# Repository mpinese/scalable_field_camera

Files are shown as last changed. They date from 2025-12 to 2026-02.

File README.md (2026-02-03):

# An Opinionated Remix of Edgar Kech's _Scalable large format field camera_

Edgar Kech has gifted the community an outstanding design in his [Scalable Field Camera](https://github.com/edgarkech/scalable_field_camera).

This is my personal remix of Edgar's work, with quality-of-life tweaks, more robust mechanical fixtures, and bugfixes. If printed in the recommended filament this camera is exceptionally lightweight, being 965 g (2.1 lb) including bellows and ground glass. I've used it in multiple photo trips now with no issues.

My remix is focused on 4&times;5 cameras only and will need tweaking for larger formats. If you're looking to print a larger camera, consider Edgar's original design.

## Changes from the original design:
- Exceptionally lightweight: 965g with bellows and ground glass.
- Threaded heat-set inserts used throughout; no more screwing into plastic.
- 3D printed knobs and lensboard, to remove reliance on hard-to-source parts.
- A more streamlined hinge.
- (Work in progress!) Harmonising the fasteners used, in an attempt to simplify the Bill of Materials.
- Many minor bugfixes
- Reorganised the source to better report the components used.
- A handle!

## Bill of Materials:
- 3D printer filament, see below for notes on filament choice. < 1 kg of filament will be needed in all cases. A small amount of TPU will be needed for the handle.
- Bellows. I followed the [Standard Camera bellows guide](https://standardcameras.com/pages/how-to-make-a-bellows) and it worked well. Note however that it's critical that the bellows material be as thin as possible; if it's too thick, the camera will not be able to close. I had success with ripstop nylon for the outer, and a very thin synthetic material used to blackout windows (black on one side, silver on the other) -- together these two were only 0.14 mm thick.
- Ground glass, 127 x 101 mm
- 600mm of 1.25mm spring steel wire
- 100mm of 0.75mm spring steel wire
- 1x brass T6 leadscrew nut (as are common on 3D printers). Ideally a double-trimmed flange type or else you will need to cut off two sides of the circular flange in order for it to fit.
- 1x T6 leadscrew, length 150 mm. Ensure that the leadscrew and nut are compatible (ie same lead and pitch).
- 3x plain washer, 6 mm, 0.8 mm thick
- 1x spring washer, 6 mm
- 1x carbon fibre rod, solid, 4 mm OD, >= 160 mm long
- 2x grub screw, M5 x 5 mm
- 4x button head machine screw, M3 x 8 mm
- 12x button head machine screw, M2 x 8 mm
- 4x countersunk machine screw, M3 x 6 mm
- 4x countersunk machine screw, M3 x 8 mm
- 23x countersunk machine screw, M3 x 10 mm
- 2x countersunk machine screw, M5 x 16 mm
- 4x countersunk machine screw, M5 x 20 mm
- 8x grub screw, M3 x 5 mm
- 10x grub screw, M3 x 8 mm
- 1x hex nut, M5
- 12x heat set insert, M2 x 3.5 x 3 (3.5 mm OD, 3 mm depth)
- 56x heat set insert, M3 x 5 x 4 (5 mm OD, 4 mm depth) -- sometimes called the "Voron" size
- 8x heat set insert, M5 x 7 x 5 (7 mm OD, 5 mm depth)

All parts are easily sourced from AliExpress.

## Filament
I used and recommend Siraya Tech's PPA-CF for this build: it is lightweight, strong, and stiff. However, it is also expensive and requires a printer with a heated chamber.

ABS is a cheaper option than PPA-CF, though it also requires a heated chamber printer, and it will likely require thicker walls than PPA-CF, thus increasing weight.

If you do not have access to a heated chamber printer then the next best option would be PLA, ideally filled (eg PLA-CF) for best printability. However, bear in mind that a PLA body will be both heavier, and less heat resistant, than the PPA-CF. This is probably not an issue in normal use, but if you were to leave your PLA camera in a hot car, it may warp.

I do not recommend PETG.

The handle will need to be printed in a flexible material like TPU.

## Printing and Assembly
- Print with 0.2 mm layer height and 15% infill throughout.
- Parts are in print orientation in the STLs.
- Support is required for the following parts:
  - `front_standard_tilt_plate_structural`
  - `rails_structural`
  - `lensboard_carrier_structural`
  - `front_standard_structural`
- Parts are labelled as "structural", "general", "control", and "flexible".
  - Structural parts should be printed in a stiff material like PPA-CF, with at least 4 walls side, top, and bottom. If using ABS or PLA, increase to at least 5 walls side, top, and bottom.
  - General and control parts can be printed in any material, with 3 walls.
  - Flexible parts should be printed in TPU with 100% infill.
- Construct following assembly.scad (open in OpenSCAD nightly version, and the full assembly with all parts will be browsable). Also consult [Edgar Kech's Scalable Field Camera](https://github.com/edgarkech/scalable_field_camera) repo for further instructions and photos.
- Note that the bellows frames each have a very thin membrane of filament that connects the inner and outer frames. This needs to be cut out to separate the two pieces of each, before the bellows can be inserted.

## Licence
CC-BY-NC-SA 4.0, see CC-BY-NC-SA-LICENSE.

## Attribution
- Original design by Edgar Kech, https://github.com/edgarkech/scalable_field_camera.
- Modifications by Mark Pinese

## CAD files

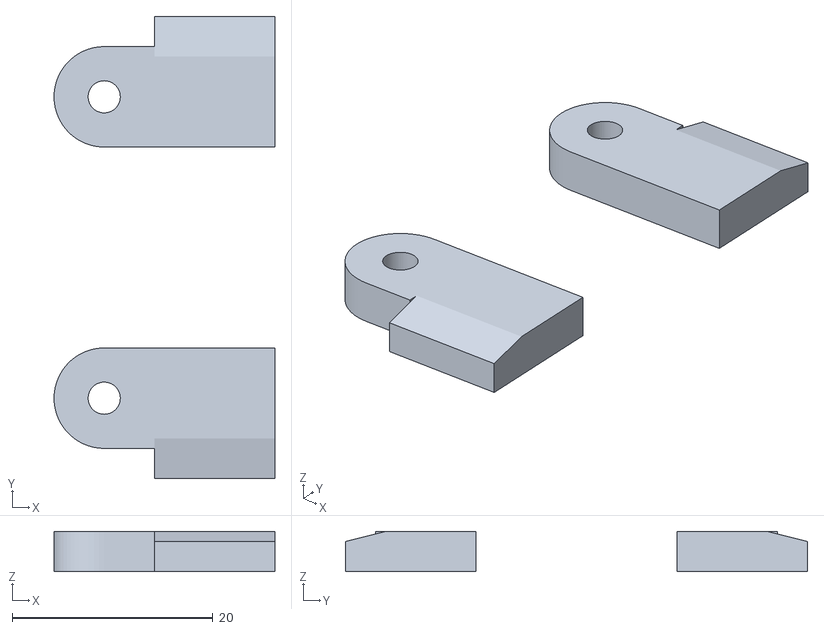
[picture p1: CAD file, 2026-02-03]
STL_4x5/locking_lever_control.stl
22.0 x 46.0 x 4.00

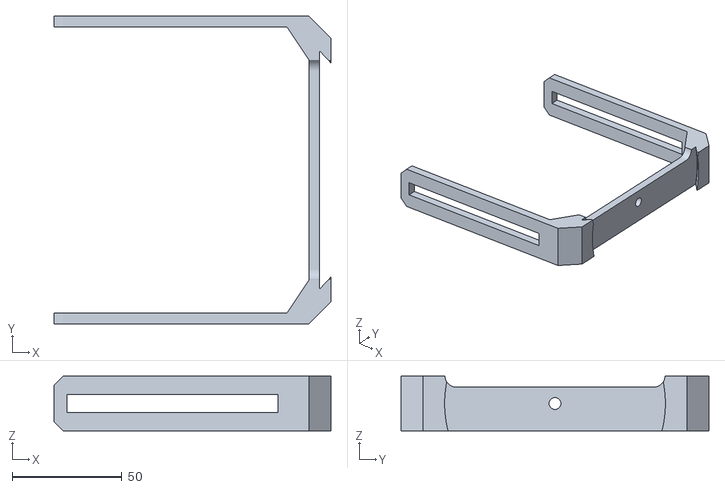
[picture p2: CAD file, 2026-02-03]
STL_4x5/front_standard_structural.stl
126.0 x 140.0 x 25.0

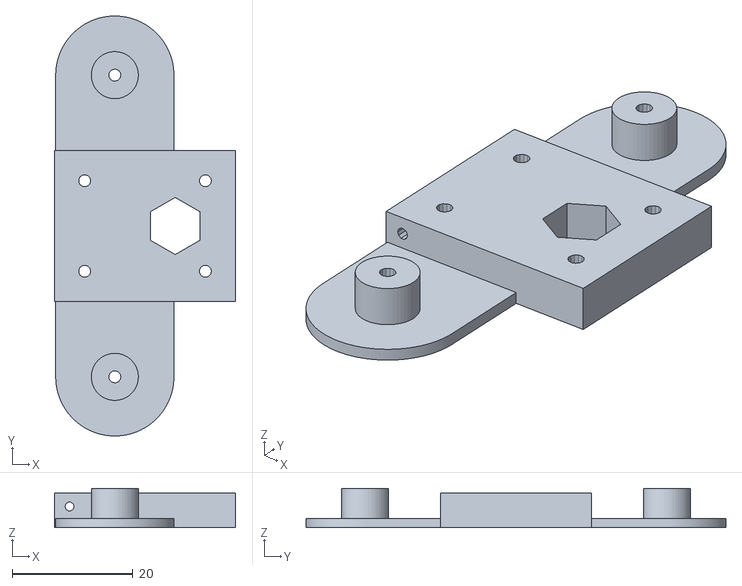
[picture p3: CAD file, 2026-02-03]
STL_4x5/pulling_lever_plate_structural.stl
30.0 x 69.6 x 6.50

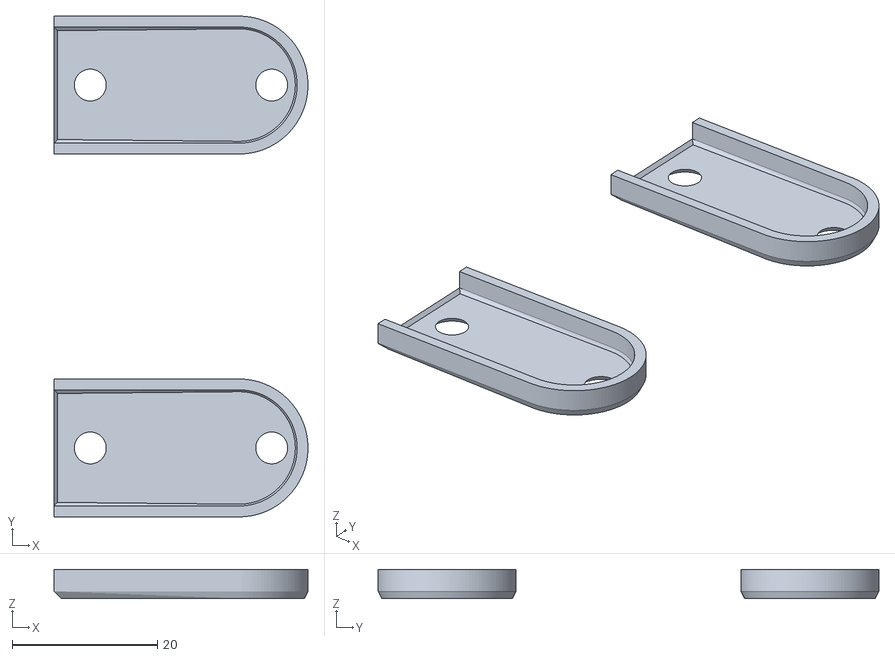
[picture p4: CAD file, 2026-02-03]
STL_4x5/handle_strap_cover_general.stl
35.0 x 69.0 x 4.00

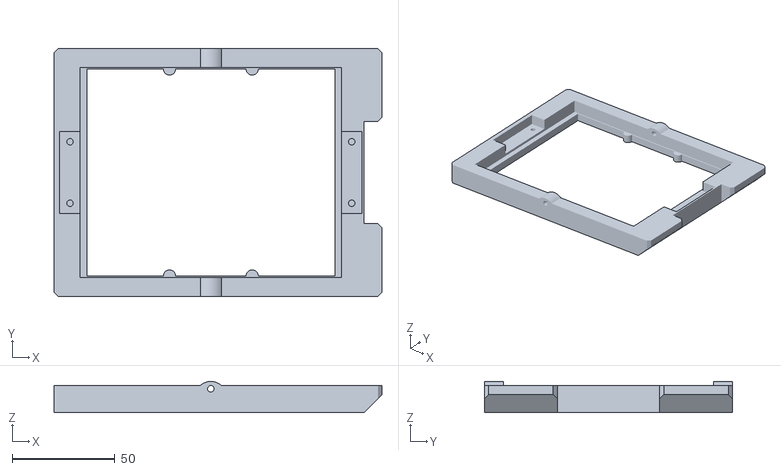
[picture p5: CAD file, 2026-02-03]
STL_4x5/ground_glass_frame_structural.stl
160.0 x 121.0 x 15.2

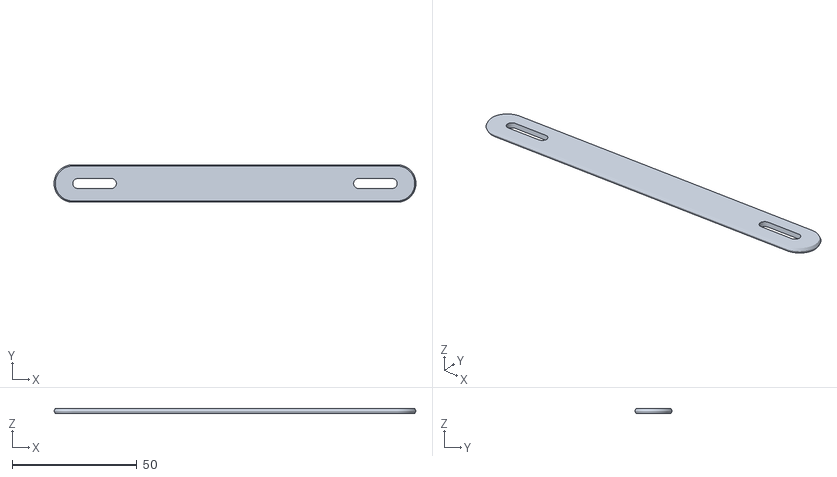
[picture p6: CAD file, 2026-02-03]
STL_4x5/handle_strap_flexible.stl
145.0 x 15.0 x 2.00

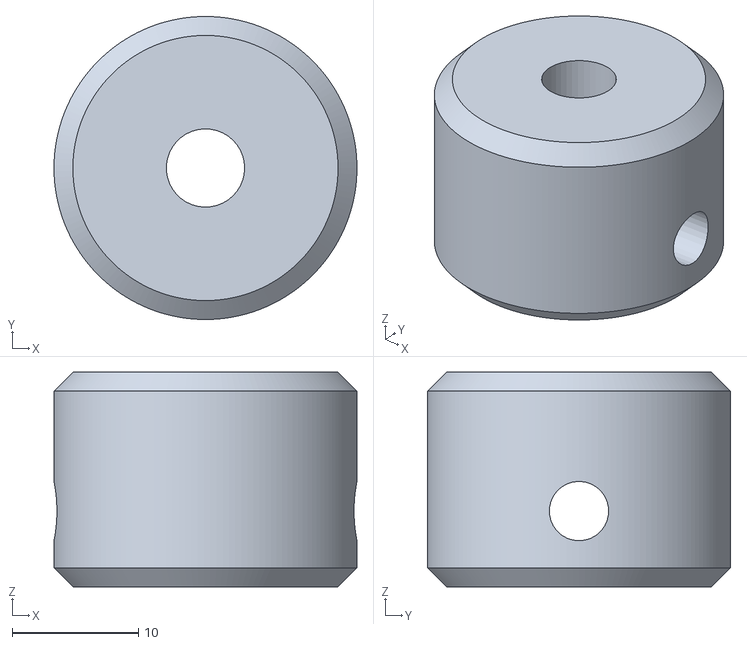
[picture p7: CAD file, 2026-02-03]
STL_4x5/focus_wheel_control.stl
24.0 x 24.0 x 17.0

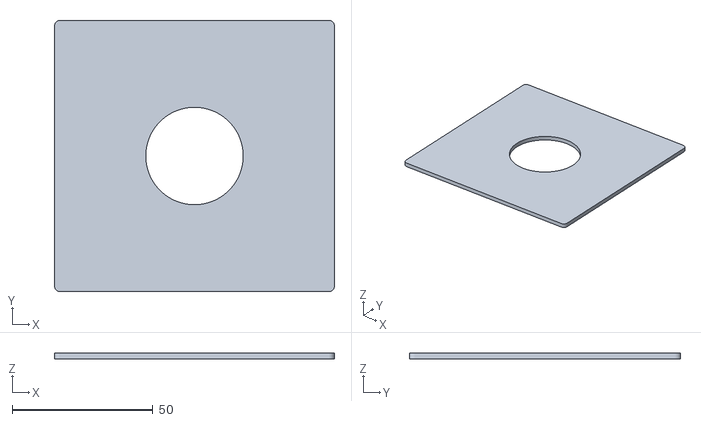
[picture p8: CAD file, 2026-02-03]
STL_4x5/lensboard_structural.stl
99.5 x 96.5 x 2.00

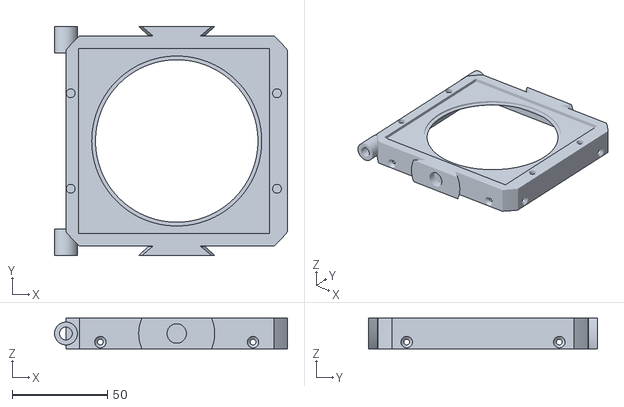
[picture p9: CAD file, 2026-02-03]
STL_4x5/lensboard_carrier_structural.stl
122.0 x 120.0 x 16.0

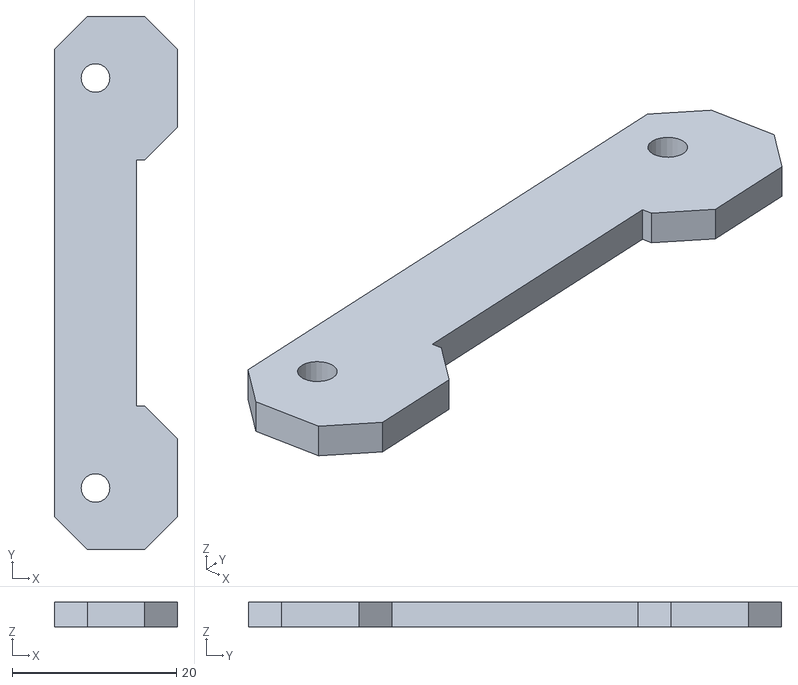
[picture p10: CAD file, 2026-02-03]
STL_4x5/lensboard_lower_clamp_control.stl
15.0 x 65.0 x 3.00

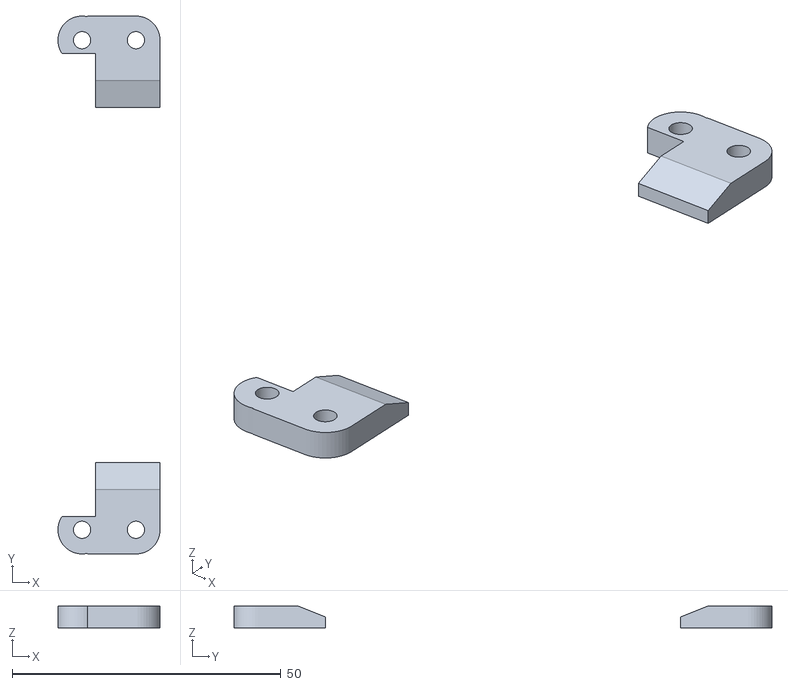
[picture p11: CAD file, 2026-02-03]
STL_4x5/locking_rail_control.stl
19.0 x 100.0 x 4.00

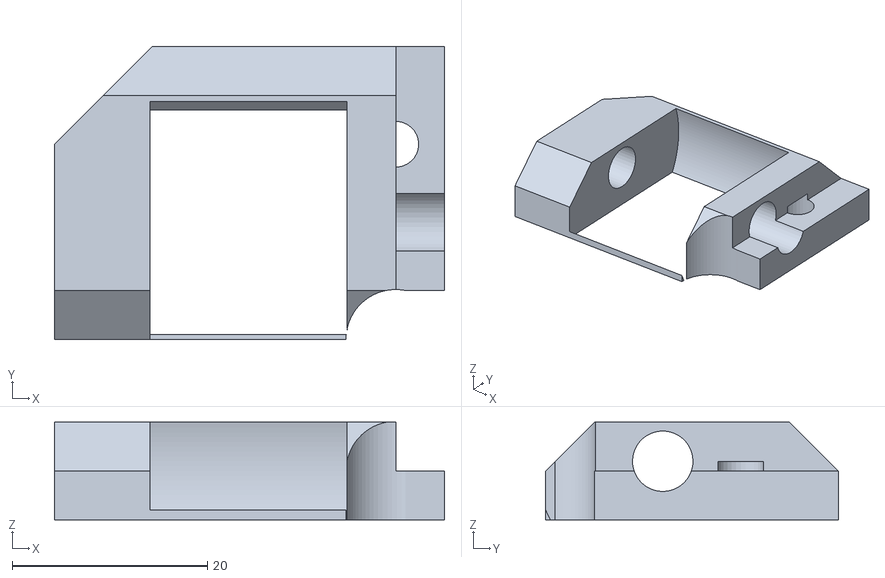
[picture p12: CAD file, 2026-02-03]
STL_4x5/focusing_block_structural.stl
40.0 x 30.0 x 10.0

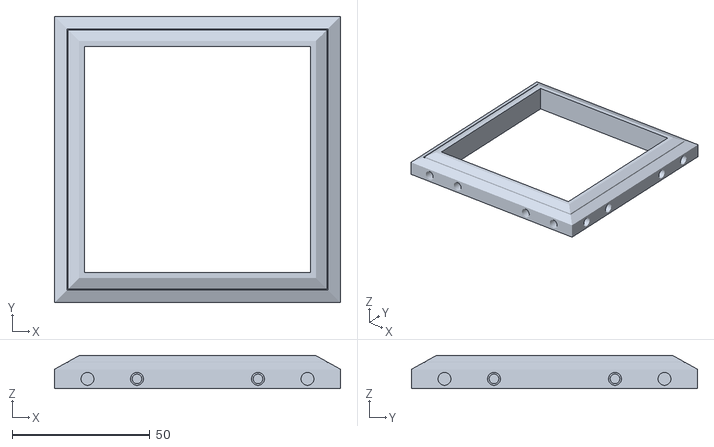
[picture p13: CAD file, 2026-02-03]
STL_4x5/bellows_front_frame_general.stl
104.0 x 104.0 x 12.0

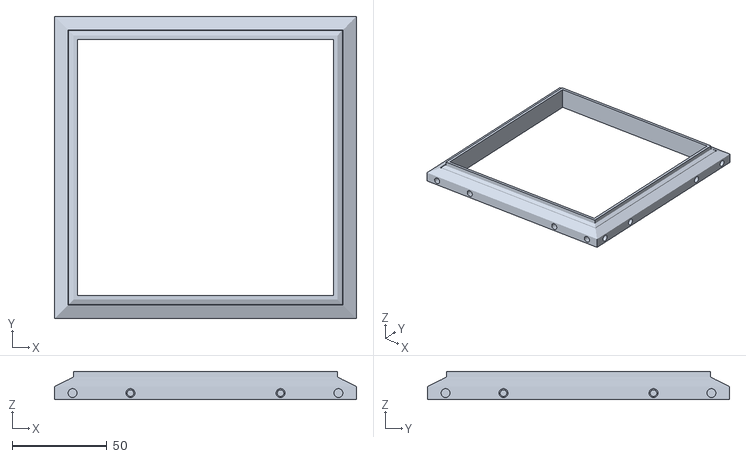
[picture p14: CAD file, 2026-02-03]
STL_4x5/bellows_back_frame_general.stl
159.0 x 159.0 x 15.0

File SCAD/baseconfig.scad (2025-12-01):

/*
Here we define some variables which are independent from the camera format
*/


// some generic variables

// we are including a format specific configuration sheet - but make sure to include only one!

include <config_4x5.scad>;
// include <config_5x7.scad>;
// include <config_8x10.scad>;

// Arca Swiss tripod plate
// caution: some Arca Swiss compatible tripod heads may have slight variations
// vArca_length = xx; // the length is irrelevant here
vArca_width = 38;
vArca_height = 7;
vArcaBase_cutout = 4;
vArcaBase_height = 1.5;

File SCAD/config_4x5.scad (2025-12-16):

/*
This is the base configuration file for the 4x5" format
# we are not using the exact ANSI measures, but slightly rounded measures for slight simplification
*/
vStabilizerTotal_h = 7;

// general tolerance
vTolerance = 0.2;

// sheet film and cassette measurements (roughly based on the ANSI measurements)
vFilmSheet_l = 127;
vFilmSheet_w = 102;
vCassette_l = 160; // A min
vCassette_w = 121; // B max
vCassette_h = 13.2; // C max
vLightTrap_l = 2; // M2
vLightTrap_w = vCassette_w;
vLightTrap_h = 1.5; // M1
vLightTrap_offsetX = 141; // G max
vFilmWindow_l = 121;
vFilmWindow_w = 101;
vFilmWindow_offsetX = 16;
vGroundGlass_offsetZ = 5;

// Graflok
vGraflok_h = 6; // this is not the official measurement, just measured from a camera 

// lens board measures (we are using Wista/Technika-style lensboards)
vLensboard_l = 100;
vLensboard_w = 97;
vLensboard_h = 2;
vLensboard_offsetX = -(vLensboard_l+3)/2; // caution: we have an asymetric offset!
vLensboard_offsetY = -vLensboard_w/2;
vLensboardHole_d = 85;
vLensboardLighttrap_d = 89;
vLensboardLighttrap_h = 1+vTolerance;

// bellows frame measures - the bellows frame design is derived from standardcameras.com
// back frame
vBellowsBackInner_l = 144; //???? check and replace with the measurement from your bellows!
vBellowsBackInner_w = vBellowsBackInner_l;
vBellowsBackOuter_l = vBellowsBackInner_l+1;
vBellowsBackOuter_w = vBellowsBackOuter_l;

vBellowsBackFrameOuter_l = 159;
vBellowsBackFrameOuter_w = vBellowsBackFrameOuter_l;
vBellowsBackFrameOuter_h = 7;
vBellowsBackFrameInner_l = 135;
vBellowsBackFrameInner_w = vBellowsBackFrameInner_l;
vBellowsBackFrameInner_h = 5;

vBellowsBackLightTrapOuter_l = vBellowsBackFrameInner_l+2*2;
vBellowsBackLightTrapOuter_w = vBellowsBackLightTrapOuter_l;
vBellowsBackLightTrap_h = 3;

//vBellowsBackFrameScrewHole_d = 2;
//vBellowsBackFrameScrewHole_h = 10;
vBellowsBackFrameScrewHole_offsetXY = 70;
vBellowsBackFrameScrewHole_offsetZ = vBellowsBackFrameOuter_h/2;

// front frame
vBellowsFrontInner_l = 94; //???? check and replace with the measurement from your bellows!
vBellowsFrontInner_w = vBellowsFrontInner_l;
vBellowsFrontOuter_l = vBellowsFrontInner_l+1;
vBellowsFrontOuter_w = vBellowsFrontOuter_l;

vBellowsFrontFrameOuter_l = 104;
vBellowsFrontFrameOuter_w = vBellowsFrontFrameOuter_l;
vBellowsFrontFrameOuter_h = 7;
vBellowsFrontFrameInner_l = 82;
vBellowsFrontFrameInner_w = vBellowsFrontFrameInner_l;
vBellowsFrontFrameInner_h = 5;

vBellowsFrontLightTrapOuter_l = vBellowsFrontFrameInner_l+2*2;
vBellowsFrontLightTrapOuter_w = vBellowsFrontLightTrapOuter_l;
vBellowsFrontLightTrap_h = 0;

//vBellowsFrontFrameScrewHole_d = 2;
//vBellowsFrontFrameScrewHole_h = 10;
vBellowsFrontFrameScrewHole_offsetXY = 40;
vBellowsFrontFrameScrewHole_offsetZ = vBellowsFrontFrameOuter_h/2;

// body dimensions
vWall_strength = 5;
vBodyOuter_l = 185; // make sure this is at least 4*vWall_strength larger than vBellowsBackFrameOuter_l!
vBodyOuter_w = 170; // make sure this is at least 2*vWall_strength larger than vBellowsBackFrameOuter_l!
vBodyOuter_h = 65;
vBodyEdge_r = vWall_strength;

// we will center our model on the Y axis and on the center of the bellows frame
// at least for the 4x5 version, we have to do an asymetric offset of 2.5mm on the X-axis 
vAsymOffsetX = -2.5;  

// back plate
vBackPlateLength = 160; // we will probably use about the same size as the bellows back frame
vBackPlateStrength = vWall_strength;

// hinges for front lid
vHingeInnerDistance = 100;
vHingeBaseWidth = 20;
vHingeHole = 4;

// lid lock measures
vLidLockBase_d = 8;
vLidLockHole_distance = 70;

// rail dimensions
vLowerRail_w = 90;
vUpperRail_w = vLowerRail_w;

// cutout for stop indents
vStopIndent_l = 4;
vStopIndent_h = 5;
vStopIndentDistance = 25; // shorter than 25 is not necessary
vStopIndent_offsetX = 20; // don't go shorter than 20 if you intend to use a 90mm lens!

// for all dovetails we use a base width of 5mm and a base height of 5mm
// we are applying tolerances to the inner AND outer part of a dovetail, in width and height
vDoveTail_w = 5;
vDoveTail_h = 5;
vDoveTail_tolerance = 0.2;

// front standard carrier / slider
// width is depending on vUpperRail_w
vSliderBase_w = vUpperRail_w + (4*vDoveTail_w);
vSliderBase_l = 40; // make sure to have enough space in the body.


// lever plate 
vLeverPlateBase_w = vUpperRail_w - (8*vDoveTail_w);
vLeverPlateBlock_w = 25;
vLeverPlateBlock_l = vSliderBase_l-(2*vDoveTail_w);

vFrontStandard_h = 126;
vFrontStandardSlot_h = vFrontStandard_h - 30;

// lensboard carrier
vFrontPlate_length = vSliderBase_w+6; // vSliderBase_w is a bit too tight for 4x5", so there we will add 5mm, for 5x7 vSliderBase_w is OK to get a squared lensboard carrier
vFrontPlate_width = vSliderBase_w; //vFrontPlate_length;
vFrontPlate_height = 16;
vEdgeCutCylinder = floor(sqrt(2*pow(vFrontPlate_width,2)))-5;

vTiltDovetailBase_d1 = 30;
vTiltDovetailBase_d2 = vTiltDovetailBase_d1+(2*vDoveTail_w);
vTiltDovetailBaseBlock_d = vTiltDovetailBase_d1+(4*vDoveTail_w);

vTiltDovetail_d1 = vTiltDovetailBase_d1-vTolerance;
vTiltDovetail_d2 = vTiltDovetailBase_d2-vTolerance;
vTiltDovetail_h = vDoveTail_w-vTolerance;

vTiltDovetailCutout_d1 = vTiltDovetailBase_d2+vTolerance;
vTiltDovetailCutout_d2 = vTiltDovetailBase_d1+vTolerance;

vAxisHole_d = 10+vTolerance;
vAxisHole_h = vDoveTail_w+vTolerance;

vTiltLockBolt_d = 12;
vTiltLockBolt_h = 14;
//vTiltLockBoltHole_d = 8;
//vTiltLockBoltHole_h = vTiltLockBolt_h;

vTiltHeight = 50;
vTiltRadius = vFrontPlate_length/2;
vTiltAngleMinus = -7;
vTiltAnglePlus = 7;
vTiltAxis_d = 10-vTolerance;

// focusing rod
vFocusingRod_d = 6;
vFocusingKnob_d = 25;
vFocusingKnob_h = 20;

// stabilizer measures (just the outer measures of our stabilizer block, not the tripod slider)
vStabilizerBase_l = 135;
vStabilizerBase_w = 90;  
vStabilizerBase_h = 7;
vStabilizerDovetailBase_w = 50;
// screw holes for the stabilizer
vLidHoleCount_x = 4;
vLidHoleDist_x = 35;
vLidHoleCount_y = 2;
vLidHoleDist_y = 60;


// screw diameters, length is individually set
vScrew1Hole_d = 3;
vScrew1ThreadHole_d = 2.2;
vScrew2Hole_d = 2;
vScrew2ThreadHole_d = 1.4;


// Dimensions for small heat set insert holes.
// Sized for M2 inserts, 3 mm depth, 3.5 mm max OD
// (may be labelled M2x3.5x3)
vInsertM2Hole_d = 3.2;
vInsertM2MinDepth_h = 4.0;
vInsertM2Size_d = 3.5;
vInsertM2Depth_h = 3.0;

// Dimensions for heat set insert holes.
// Sized for "Voron standard" M3 inserts, 4 mm depth, 5 mm max OD
// (variously labelled M3x4x5 or M3x5x4)
vInsertM3Hole_d = 4.7;
vInsertM3MinDepth_h = 5.0;
vInsertM3Size_d = 5.0;
vInsertM3Depth_h = 4.0;

// Dimensions for large heat set insert holes.
// Sized for M5 inserts, 5 mm depth, 7 mm max OD
// (may be labelled M5x7x5)
vInsertM5Hole_d = 6.7;
vInsertM5MinDepth_h = 6.0;
vInsertM5Size_d = 7.0;
vInsertM5Depth_h = 5.0;


// Handle strap
vHandleStrap_h = 2.0;       // Thickness of the strap in mm
vHandleStrap_w = 15.0;      // Width of the strap in mm
vHandleStrap_l = 145.0;     // Total length of the strap in mm
vHandleStrapMovement_l = 35.0;   // Total amount the strap moves, in mm. Each side moves half this amount.
vHandleStrapCutout_w = 4.0;      // Width of the central cutout, in mm
vHandleStrapSlotOffsetFar = vHandleStrap_l/2 - vHandleStrap_w/2;
vHandleStrapSlotOffsetNear = vHandleStrapSlotOffsetFar - vHandleStrapMovement_l/2;
vHandleStrapCoverExtra_l = 5.0;
vHandleStrapHoleSize_d = 3.0;
vStrapHoleDelta = vHandleStrapSlotOffsetNear-vHandleStrapCoverExtra_l+vHandleStrapHoleSize_d/2;
vStrapHoleSpacing = vHandleStrapMovement_l/2 + vHandleStrap_w/2;

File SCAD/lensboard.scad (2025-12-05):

// loading the base configuration
include <baseconfig.scad>;

vOuterSize_w = vLensboard_l-0.5;
vOuterSize_h = vLensboard_w-0.5;
vHoleSize_d = 34.6;
vThickness_d = vLensboard_h;
vFillet_r = 2.0;

vOffset_w = vOuterSize_w/2-vFillet_r;
vOffset_h = vOuterSize_h/2-vFillet_r;

module lensboard() {

difference() {
    hull() {
        translate([vOffset_w, vOffset_h, 0]) cylinder(h=vThickness_d, r=vFillet_r);
        translate([-vOffset_w, vOffset_h, 0]) cylinder(h=vThickness_d, r=vFillet_r);
        translate([vOffset_w, -vOffset_h, 0]) cylinder(h=vThickness_d, r=vFillet_r);
        translate([-vOffset_w, -vOffset_h, 0]) cylinder(h=vThickness_d, r=vFillet_r);
    };
    
    translate([0, 0, -1]) cylinder(h=vThickness_d+2, d=vHoleSize_d);
}
 
}

lensboard();

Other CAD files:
STL_4x5/back_plate_structural.stl
STL_4x5/lensboard_upper_clamp_control.stl
STL_4x5/pulling_lever_control.stl
STL_4x5/front_lid_dovetail_structural.stl
SCAD/lensboard_carrier.scad
SCAD/assembly.scad
SCAD/back_plate.scad
SCAD/bellows_back_frame.scad
SCAD/bellows_front_frame.scad
SCAD/body.scad
SCAD/focus_wheel.scad
SCAD/focusing_block.scad
SCAD/front_lid.scad
SCAD/front_lid_dovetail.scad
SCAD/front_standard.scad
SCAD/front_standard_tilt_plate.scad
SCAD/ground_glass_clamp.scad
SCAD/ground_glass_frame.scad
SCAD/handle_strap.scad
SCAD/handle_strap_cover.scad
SCAD/lensboard_lower_clamp.scad
SCAD/lensboard_upper_clamp.scad
SCAD/locking_lever.scad
SCAD/locking_rail.scad
SCAD/modules.scad
SCAD/pulling_lever.scad
SCAD/pulling_lever_plate.scad
SCAD/rails.scad
SCAD/slider.scad
SCAD/thumbscrews.scad
SCAD/tripod_plate.scad
STL_4x5/body_structural.stl
STL_4x5/front_lid_structural.stl
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

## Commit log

2025-11-27 Refactoring and bug fixes. * Refactor: Moved all parts to modules. * Refactor: Added high-level assembly.scad which arranges parts in assembled locations. * Bugfix: Fixed front_lid_dovetail hole loca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
    [assembly.scad, back_plate.scad, bellows_back_frame.scad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]
2025-11-27 Changed front lid mounting to M3 heat-set inserts
    [config_4x5.scad, front_lid.scad, front_lid_dovetail.scad]
2025-11-27 Added hex screw module for fit testing. Confirmed 10 mm screw is suitable for front lid dovetail mounting.
    [assembly.scad, modules.scad]
2025-11-27 Fixed knurling on focus wheel.
    [focus_wheel.scad]
2025-11-27 Changed block mounting to M3 heat-set inserts.
    [focusing_block.scad]
2025-11-27 Changed holes to accept heat-set inserts
    [config_4x5.scad, focus_wheel.scad, lensboard_carrier.scad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]
2025-11-27 Further conversion to heat-set inserts.
    [assembly.scad, bellows_back_frame.scad, bellows_front_frame.scad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]
2025-11-28 Converted body M5 mount (locking hole) to heat-set insert
    [body.scad, config_4x5.scad, modules.scad]
2025-11-28 Started adding screws and inserts into assembly
    [assembly.scad, bellows_back_frame.scad, bellows_front_frame.scad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]
2025-11-29 Fixed a bug in countersunk_screw where d2 was unspecified (and therefore defaulted to 1.0). Countersinking now has the correct 90deg angle for metric screws.
    [modules.scad]
2025-11-29 Added inserts for bellows mounting holes.
    [assembly.scad, bellows_back_frame.scad]
2025-11-29 More insert conversion.
    [assembly.scad, ground_glass_frame.scad, modules.scad]
2025-11-29 Fixed horizontal bellows screws countersinking.
    [lensboard_carrier.scad]
2025-11-29 Fixed bellows screw locations not matching the bellows. Fixed incorrect countersink angles.
    [lensboard_carrier.scad]
2025-11-29 Fixed incorrect insert location
    [bellows_back_frame.scad]
2025-11-29 Further insert conversion.
    [assembly.scad, bellows_front_frame.scad, config_4x5.scad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]
2025-11-29 More modules added. Added BOM echo statements.
    [assembly.scad, modules.scad]
2025-11-30 Changed bellows mounting to grub screws in blind holes
    [assembly.scad, bellows_back_frame.scad, bellows_front_frame.scad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]
2025-11-30 Changed colours to match print settings.
    [assembly.scad, focus_wheel.scad, modules.scad]
2025-11-30 Initial modifications to implement blind hinge
    [assembly.scad, front_lid.scad]
2025-12-01 Fixed hinge, added lensboard, visual changes
    [assembly.scad, baseconfig.scad, config_4x5.scad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]
2025-12-01 Fixed bellows alignment, started adding handle
    [assembly.scad, handle_strap.scad]
2025-12-04 Fixed clamp locations, moved handle
    [assembly.scad]
2025-12-05 Added handle
    [assembly.scad, body.scad, config_4x5.scad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]
2025-12-05 Added new parts to print code
    [assembly.scad]
2025-12-05 Added chamfers to handle strap
    [handle_strap.scad]
2025-12-05 Moved to Makefile building
    [assembly.scad, back_plate.stl, back_plate_structural.stl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]
2025-12-05 Added allowance for lensboard fit
    [assembly.scad, lensboard.scad]
2025-12-06 Changed front standard print orientation
    [front_standard.scad]
2025-12-16 Multiple bug fixes
    [assembly.scad, body.scad, config_4x5.scad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]
2025-12-16 Fixed leadscrew nut location
    [assembly.scad]
2025-12-16 Fixed insert locations
    [assembly.scad]
2025-12-16 Removing stale STLs
    [back_plate_structural.stl, bellows_back_frame_general.stl, bellows_front_frame_general.stl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]
2025-12-16 Removed cover as it was impeding closing
    [focusing_block.scad]
2025-12-18 Fixed front standard sizing and added chamfer
    [assembly.scad, front_standard.scad]
2026-01-05 Fixed locking rail sizing to allow portrait mode conversion. Added M5 thread holder to stow tripod mount screw.
    [assembly.scad, front_lid.scad, locking_rail.scad]
2026-02-03 Added design for basic focus loupe
    [focus_loupe.scad]
2026-02-03 Removed potentially stale STLs
    [back_plate.stl, bellows_back_frame.stl, bellows_front_frame.stl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]
2026-02-03 Updated README and STLs. Removed old unused focus loupe design
    [back_plate_structural.stl, bellows_back_frame_general.stl, bellows_front_frame_general.stl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]
2026-02-03 Fixed orientation and offset of thumbscrews.
    [thumbscrews.scad, thumbscrews_control.stl]
2026-02-03 Fixed missing locking lever and print orientation issue
    [locking_lever.scad, locking_lever_control.stl]
